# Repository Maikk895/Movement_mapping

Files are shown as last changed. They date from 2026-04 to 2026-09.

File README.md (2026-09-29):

Schemat projektu:




Layout płytki:






Wizualizacja:



Gotowy projekt:



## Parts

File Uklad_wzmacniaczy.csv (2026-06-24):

'Reference' | 'Qty' | 'Value' | 'DNP' | 'Exclude from BOM' | 'Exclude from Board' | 'Footprint' | 'Datasheet'
'BT1' | '1' | 'BK-18650-PC2' | '' | '' | '' | 'Uklad_wzmacniaczy_footprints:BAT_BK-18650-PC2' | 'https://www.digikey.co.uk/en/products/detail/mpd-memory-protection-devices/BK-18650-PC2/2079908'
'C1,C2,C3,C6,C10,C11,C16,C21,C23,C27,C31,C34,C35,C42,C43' | '15' | '10u' | '' | '' | '' | 'Capacitor_SMD:C_0603_1608Metric_Pad1.08x0.95mm_HandSolder' | ''
'C4,C5,C8,C9,C12,C17,C19,C20,C22,C24,C28,C44,C45,C46,C47' | '15' | '100n' | '' | '' | '' | 'Capacitor_SMD:C_0603_1608Metric_Pad1.08x0.95mm_HandSolder' | ''
'C7,C13,C18' | '3' | '1n' | '' | '' | '' | 'Capacitor_SMD:C_0603_1608Metric_Pad1.08x0.95mm_HandSolder' | ''
'C14,C15,C41' | '3' | '10n' | '' | '' | '' | 'Capacitor_SMD:C_0603_1608Metric_Pad1.08x0.95mm_HandSolder' | ''
'C25,C26,C30,C32,C33' | '5' | '4.7u' | '' | '' | '' | 'Capacitor_SMD:C_0603_1608Metric_Pad1.08x0.95mm_HandSolder' | ''
'C29' | '1' | '0.47u' | '' | '' | '' | 'Capacitor_SMD:C_0603_1608Metric_Pad1.08x0.95mm_HandSolder' | ''
'C36' | '1' | '1u' | '' | '' | '' | 'Capacitor_SMD:C_0603_1608Metric_Pad1.08x0.95mm_HandSolder' | ''
'C37' | '1' | '10p' | '' | '' | '' | 'Capacitor_SMD:C_0603_1608Metric_Pad1.08x0.95mm_HandSolder' | ''
'C38,C39,C40' | '3' | '22u' | '' | '' | '' | 'Capacitor_SMD:C_0603_1608Metric_Pad1.08x0.95mm_HandSolder' | ''
'D1' | '1' | 'LED' | '' | '' | '' | 'LED_SMD:LED_0805_2012Metric_Pad1.15x1.40mm_HandSolder' | ''
'J1' | '1' | 'SJ1-3523N' | '' | '' | '' | 'Uklad_wzmacniaczy_footprints:CUI_SJ1-3523N' | ''
'J2' | '1' | 'MEM2080-00-128-00-A' | '' | '' | '' | 'Uklad_wzmacniaczy_footprints:CONN_MEM2080-00-128-00-A_GCT' | 'MEM2080-00-128-00-A'
'J3' | '1' | 'Conn_01x10_Pin' | '' | '' | '' | 'Connector_PinHeader_2.54mm:PinHeader_2x05_P2.54mm_Horizontal' | ''
'L1' | '1' | '2.2u' | '' | '' | '' | 'Uklad_wzmacniaczy_footprints:INDC2520X120N' | ''
'L2' | '1' | '1u' | '' | '' | '' | 'Uklad_wzmacniaczy_footprints:IND_SPM6530T-1R0M120' | ''
'R1,R5,R7' | '3' | '33' | '' | '' | '' | 'Resistor_SMD:R_0603_1608Metric_Pad0.98x0.95mm_HandSolder' | ''
'R2,R9' | '2' | '220k' | '' | '' | '' | 'Resistor_SMD:R_0603_1608Metric_Pad0.98x0.95mm_HandSolder' | ''
'R3,R11' | '2' | '523' | '' | '' | '' | 'Resistor_SMD:R_0603_1608Metric_Pad0.98x0.95mm_HandSolder' | ''
'R4,R10' | '2' | '200-400k' | '' | '' | '' | 'Resistor_SMD:R_0603_1608Metric_Pad0.98x0.95mm_HandSolder' | ''
'R6,R8' | '2' | '10k' | '' | '' | '' | 'Resistor_SMD:R_0603_1608Metric_Pad0.98x0.95mm_HandSolder' | ''
'R12,R15' | '2' | '49.9k' | '' | '' | '' | 'Resistor_SMD:R_0603_1608Metric_Pad0.98x0.95mm_HandSolder' | ''
'R13' | '1' | '365k' | '' | '' | '' | 'Resistor_SMD:R_0603_1608Metric_Pad0.98x0.95mm_HandSolder' | ''
'R14' | '1' | '120k' | '' | '' | '' | 'Resistor_SMD:R_0603_1608Metric_Pad0.98x0.95mm_HandSolder' | ''
'R16' | '1' | '487k' | '' | '' | '' | 'Resistor_SMD:R_0603_1608Metric_Pad0.98x0.95mm_HandSolder' | ''
'R17' | '1' | '1M' | '' | '' | '' | 'Resistor_SMD:R_0603_1608Metric_Pad0.98x0.95mm_HandSolder' | ''
'R18' | '1' | '332k' | '' | '' | '' | 'Resistor_SMD:R_0603_1608Metric_Pad0.98x0.95mm_HandSolder' | ''
'R19' | '1' | '2k' | '' | '' | '' | 'Resistor_SMD:R_0603_1608Metric_Pad0.98x0.95mm_HandSolder' | ''
'R20' | '1' | '41.2k' | '' | '' | '' | 'Resistor_SMD:R_0603_1608Metric_Pad0.98x0.95mm_HandSolder' | ''
'U1' | '1' | 'OPA2388IDR' | '' | '' | '' | 'Uklad_wzmacniaczy_footprints:D0008A-IPC_A' | 'https://www.ti.com/lit/gpn/opa2388'
'U2' | '1' | 'REF2033QDDCRQ1' | '' | '' | '' | 'Uklad_wzmacniaczy_footprints:SOT-23-THIN-5_DDC_TEX' | 'https://www.ti.com/lit/gpn/ref20-q1'
'U3,U5' | '2' | 'AD8421ARMZ' | '' | '' | '' | 'Uklad_wzmacniaczy_footprints:RM_8_ADI' | 'https://www.analog.com/media/en/technical-documentation/data-sheets/AD8421-EP.pdf'
'U4' | '1' | 'OPA388IDR' | '' | '' | '' | 'Uklad_wzmacniaczy_footprints:D8_TEX' | 'https://www.ti.com/lit/gpn/opa388'
'U6' | '1' | 'TPD4E1B06DRLR' | '' | '' | '' | 'Uklad_wzmacniaczy_footprints:SOT50P160X60-6N' | ''
'U7,U10,U11' | '3' | 'AD5162BRMZ10-RL7' | '' | '' | '' | 'Uklad_wzmacniaczy_footprints:RM_10_ADI' | 'https://www.analog.com/media/en/technical-documentation/data-sheets/AD5162.pdf'
'U8' | '1' | 'LT3042EMSE-TRPBF' | '' | '' | '' | 'Uklad_wzmacniaczy_footprints:05-08-1664_ADI' | 'https://www.analog.com/media/en/technical-documentation/data-sheets/lt3042.pdf'
'U9' | '1' | 'TPS65135RTER' | '' | '' | '' | 'Uklad_wzmacniaczy_footprints:RTE16_1P7X1P7' | 'https://www.digikey.co.uk/en/products/detail/texas-instruments/TPS65135RTER/2782705'
'U12' | '1' | 'LT3094EMSE-TRPBF' | '' | '' | '' | 'Uklad_wzmacniaczy_footprints:MSE_05-08-1666_ADI' | 'https://www.analog.com/media/en/technical-documentation/data-sheets/LT3094.pdf'
'U13' | '1' | 'Nucleo-H755ZIQ-Morpho' | '' | '' | '' | 'Uklad_wzmacniaczy_footprints:Nucleo-H755ZIQ-Morpho' | ''
'U14' | '1' | 'TPS61236PRWLR' | '' | '' | '' | 'Uklad_wzmacniaczy_footprints:RWL0009A' | 'https://www.ti.com/lit/gpn/tps61236p'
'U15' | '1' | 'LD1117S50TR_SOT223' | '' | '' | '' | 'Package_TO_SOT_SMD:SOT-223-3_TabPin2' | 'http://www.st.com/st-web-ui/static/active/en/resource/technical/document/datasheet/CD00000544.pdf'

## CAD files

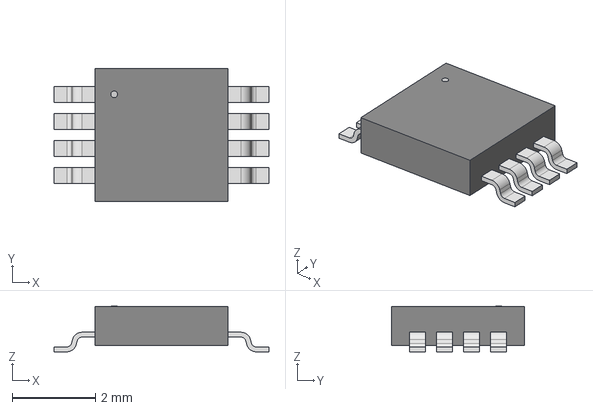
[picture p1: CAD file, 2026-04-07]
Parts/AD8421ARMZ/RM_8_ADI.step
5.16 x 3.20 x 1.09 mm

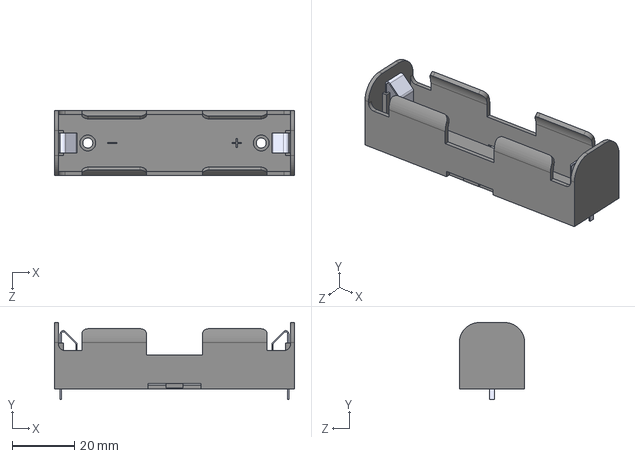
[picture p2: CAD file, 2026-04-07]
Parts/BK_18650_PC2/BK-18650-PC2.step
77.0 x 24.7 x 21.0 mm

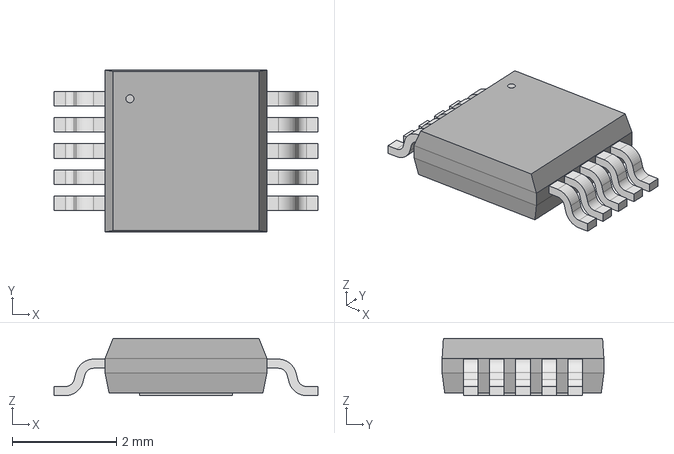
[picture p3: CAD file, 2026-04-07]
Parts/LT3042EMSE_TRPBF/05-08-1664_ADI.step
5.05 x 3.10 x 1.09 mm

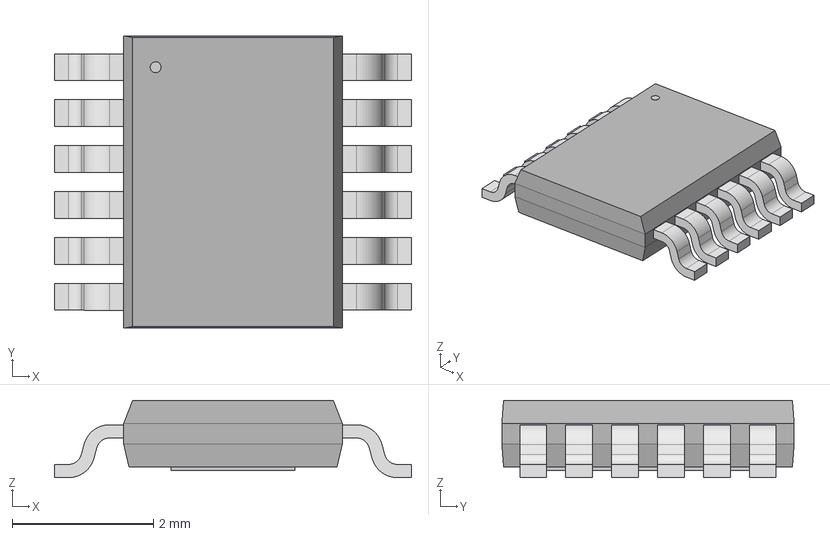
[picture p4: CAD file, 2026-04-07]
Parts/LT3094EMSE_TRPBF/MSE_05-08-1666_ADI.step
5.05 x 4.14 x 1.09 mm

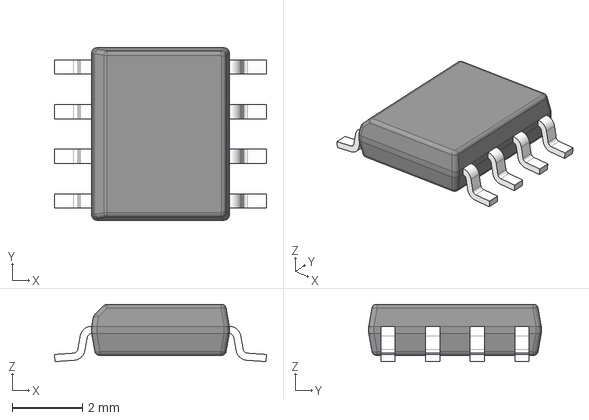
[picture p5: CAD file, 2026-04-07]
Parts/OPA189IDR/D0008A.stp
6.02 x 4.90 x 1.63 mm
BODY-SO
LEAD-D0008A x 8

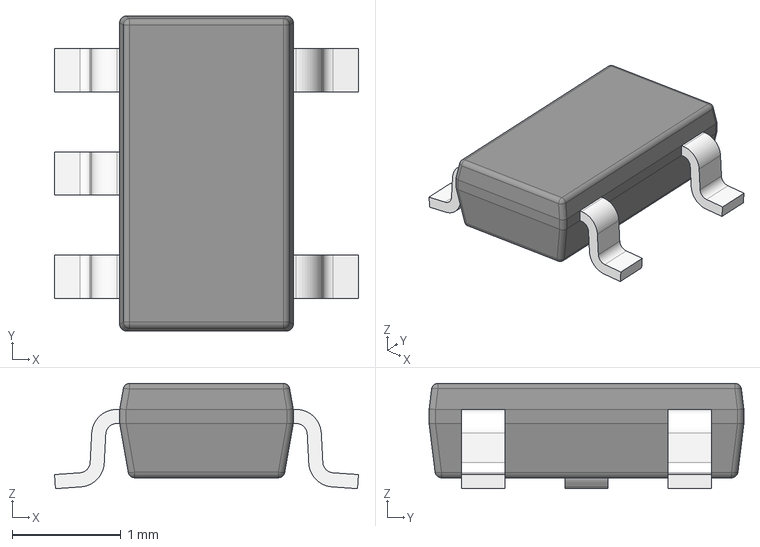
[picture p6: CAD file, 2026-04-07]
Parts/REF2033QDDCRQ1/DDC0005A.stp
2.80 x 2.90 x 0.97 mm
BODY-SOT
LEAD-SOT x 5

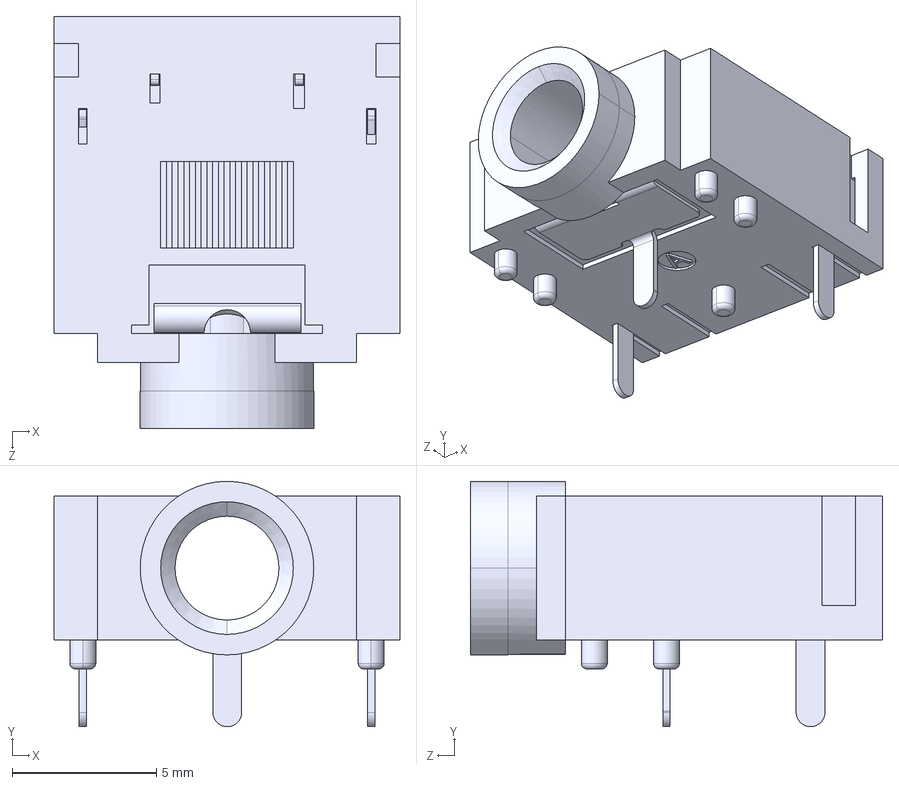
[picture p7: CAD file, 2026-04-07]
Parts/SJ1_3523N/SJ1-3523N.step
12.0 x 8.51 x 14.3 mm

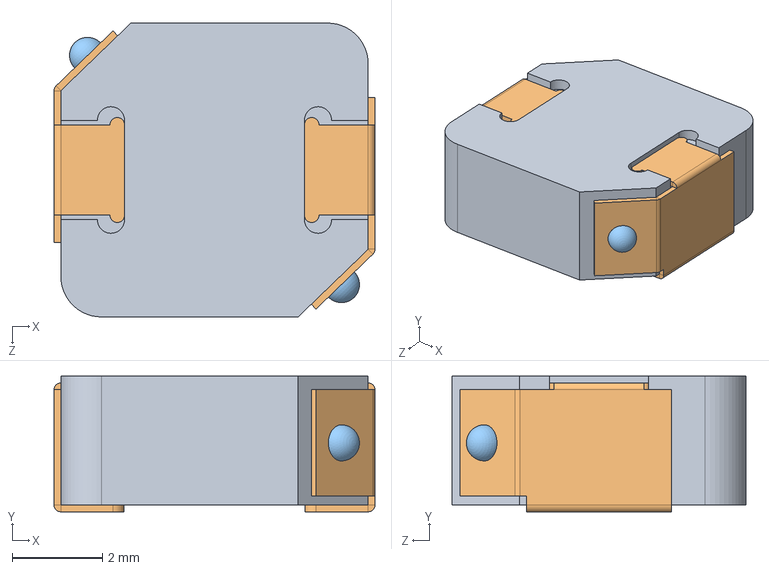
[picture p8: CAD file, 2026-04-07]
Parts/SPM6530T_1R0M120/SPM6530T-1R0M120.step
7.10 x 3.00 x 6.50 mm

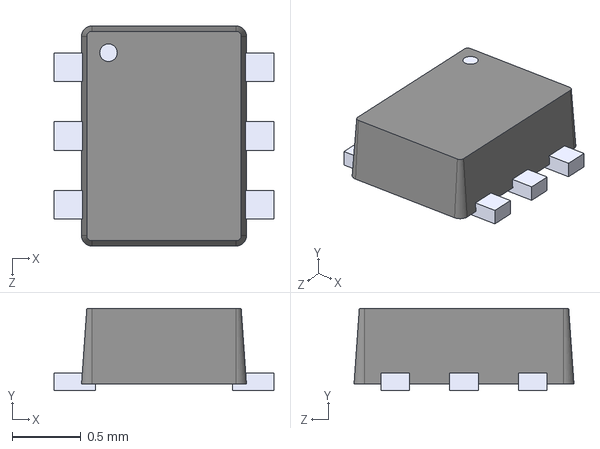
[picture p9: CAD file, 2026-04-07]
Parts/TPD4E1B06DRLR/TPD4E1B06DRLR.step
1.60 x 0.6 x 1.60 mm

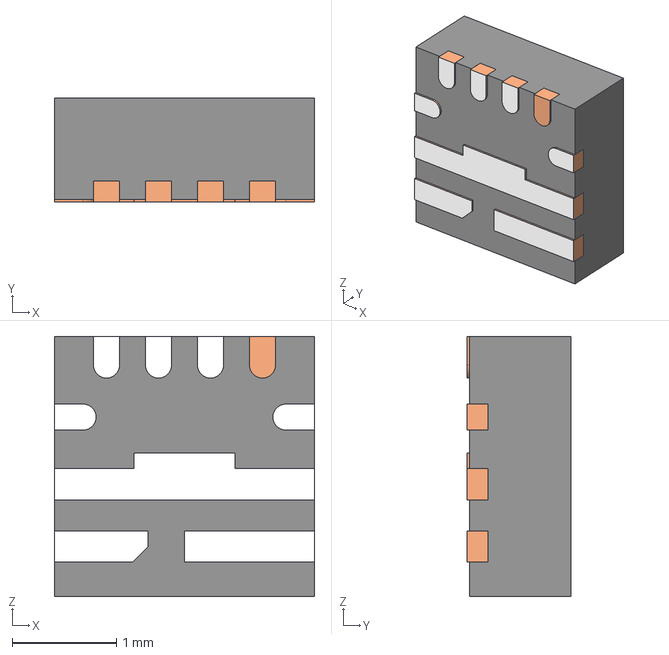
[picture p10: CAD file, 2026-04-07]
Parts/TPS61236PRWLR/RWL0009A.stp
2.50 x 1.00 x 2.50 mm
FRAME-RWL0009A
BODY-QFN

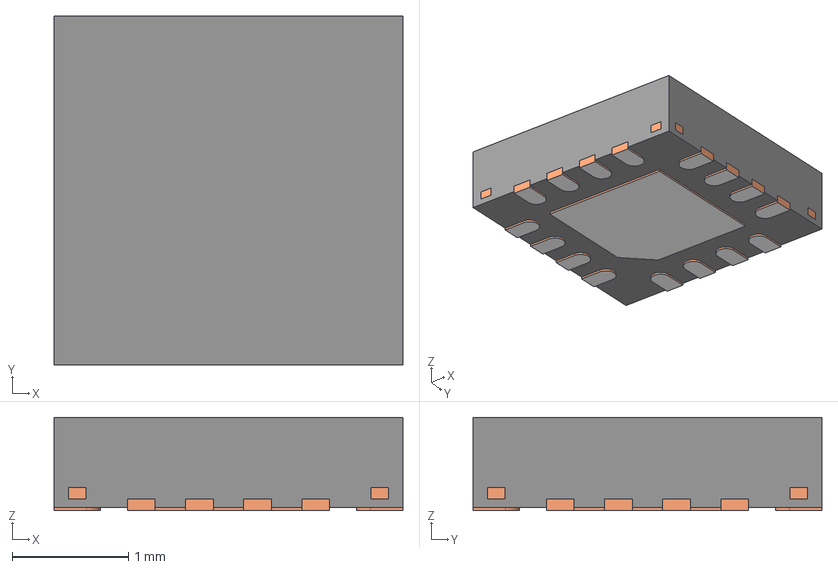
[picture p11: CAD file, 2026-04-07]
Parts/TPS65135RTER/RTE0016C.stp
3.00 x 3.00 x 0.8 mm
BODY-QFN
FRAME-RTE0016C
PIN1-ID

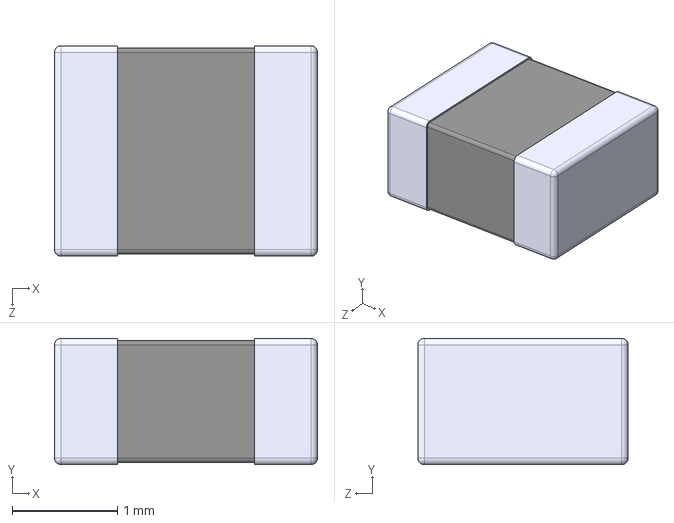
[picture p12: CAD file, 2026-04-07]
Parts/DFE252012P_2R2M_P2/DFE252012P-2R2M_P2.step
2.50 x 1.20 x 2.00 mm

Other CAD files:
Parts/OPA2388IDR/D0008A.stl

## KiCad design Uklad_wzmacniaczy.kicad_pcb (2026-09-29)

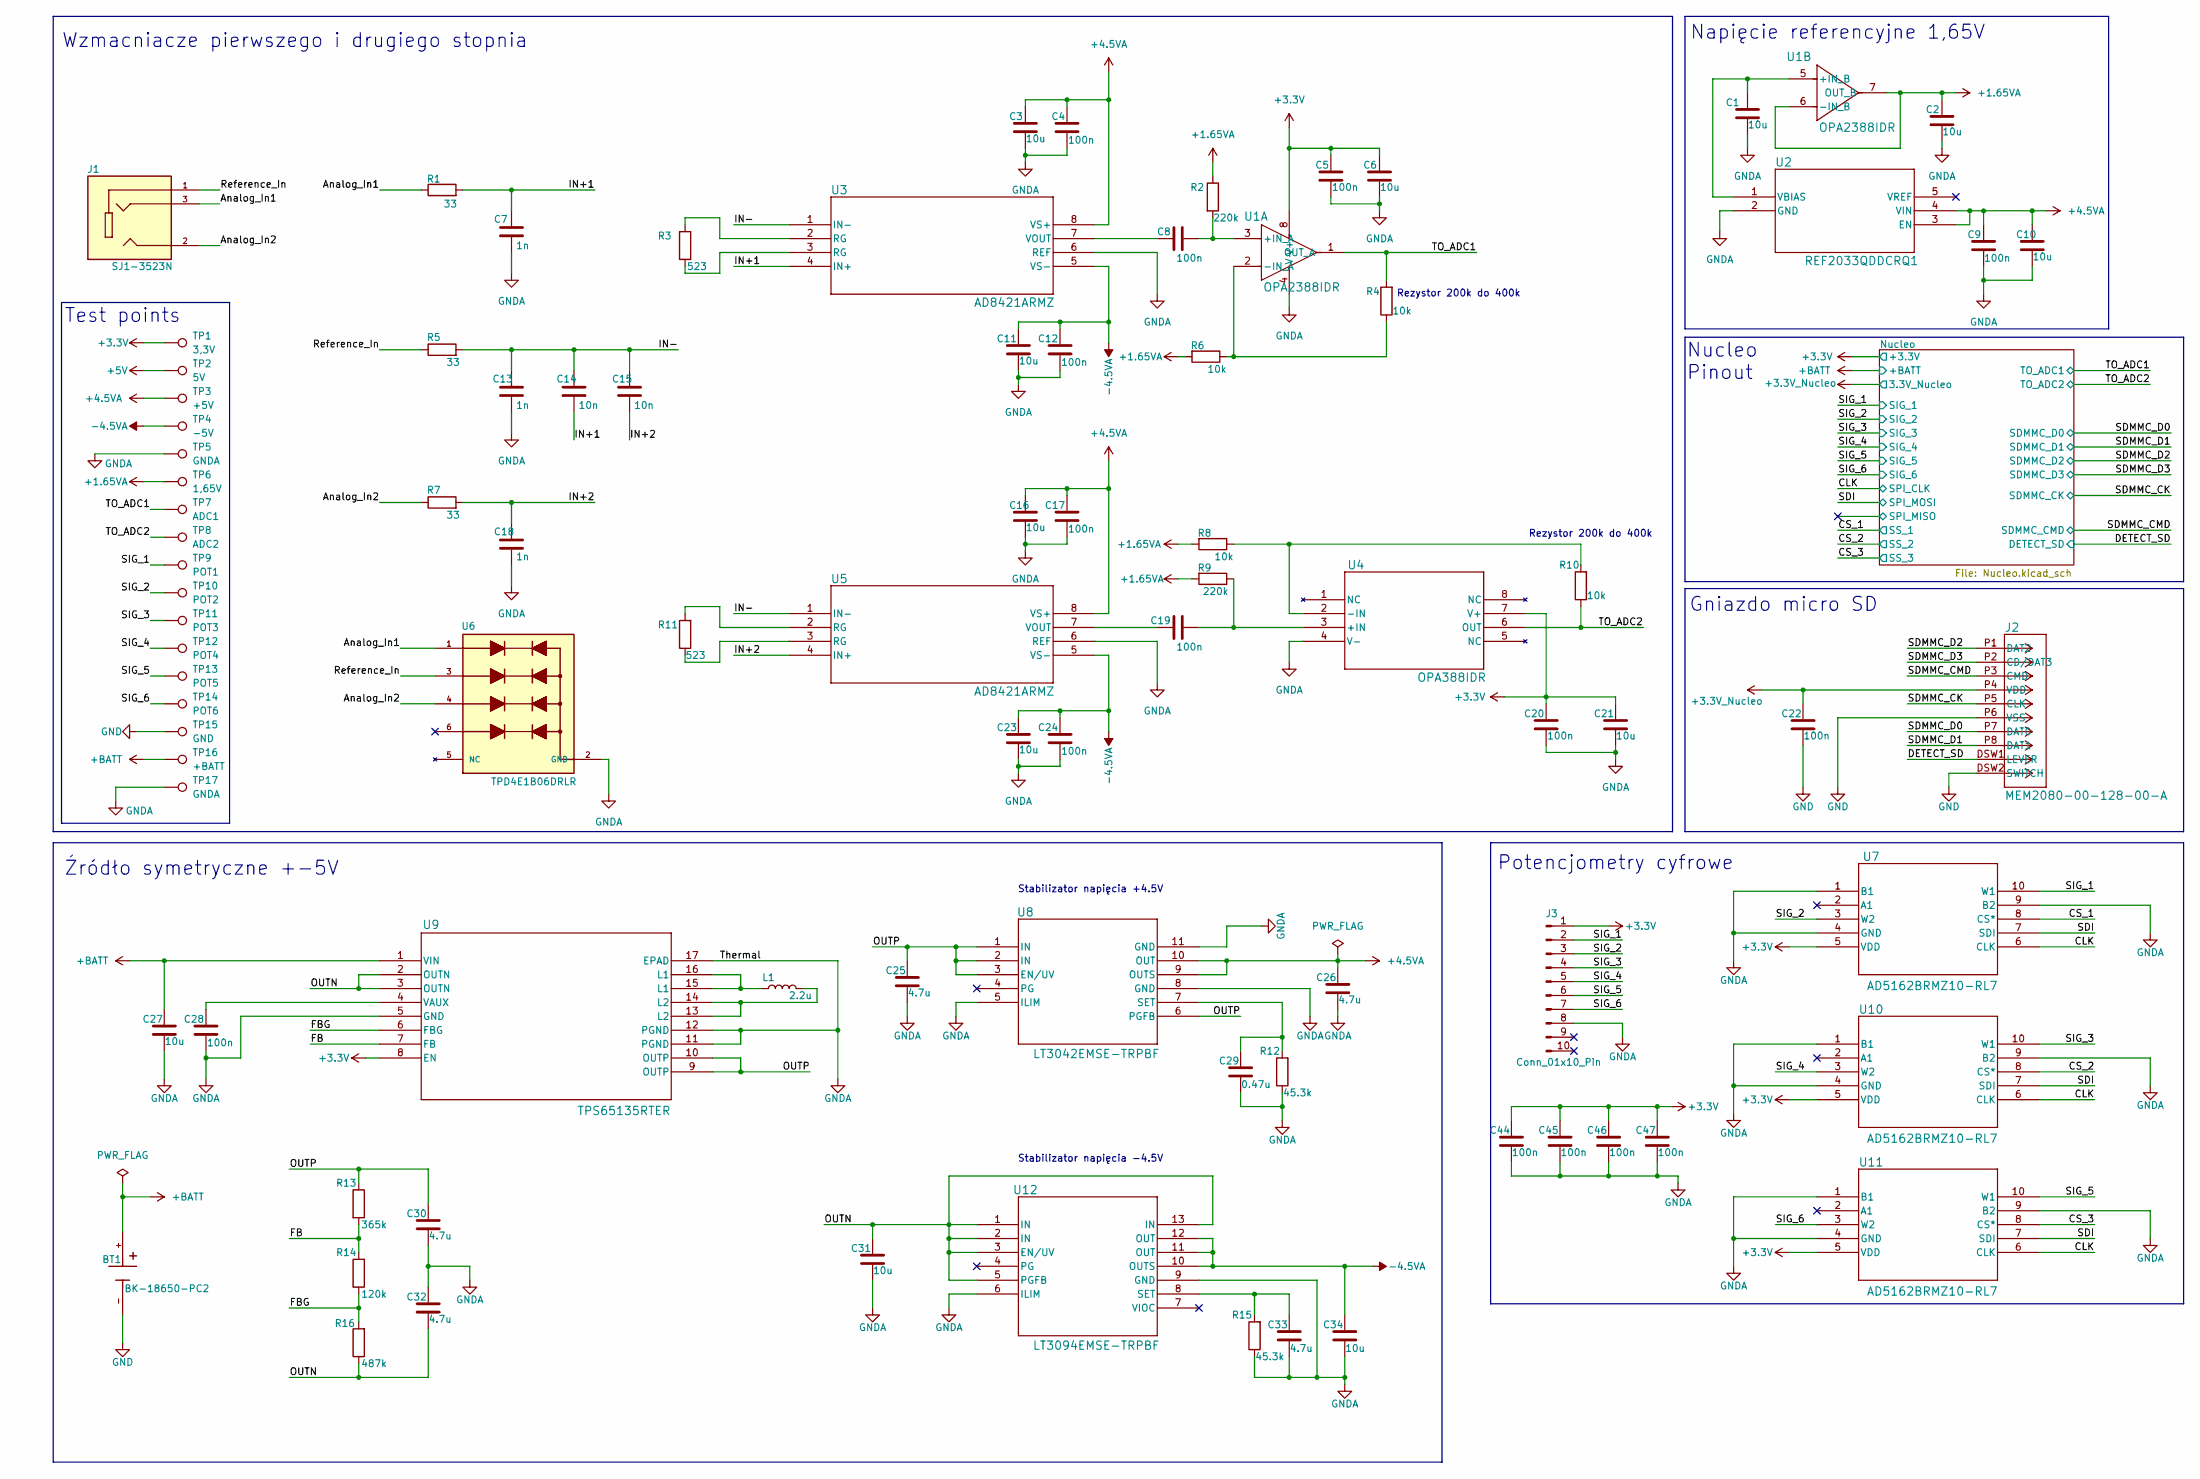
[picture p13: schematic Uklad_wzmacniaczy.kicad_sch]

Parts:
BT1: BK-18650-PC2; BAT_BK-18650-PC2; PARTREV F
C1, C2, C3, C6, C10, C11, C16, C21, C23, C27, C31, C34: 10u; C_0603_1608Metric_Pad1.08x0.95mm_HandSolder
C4, C5, C8, C9, C12, C17, C19, C20, C22, C24, C28, C44, C45, C46, C47: 100n; C_0603_1608Metric_Pad1.08x0.95mm_HandSolder
C7, C13, C18: 1n; C_0603_1608Metric_Pad1.08x0.95mm_HandSolder
C14, C15: 10n; C_0603_1608Metric_Pad1.08x0.95mm_HandSolder
C25, C26, C30, C32, C33: 4.7u; C_0603_1608Metric_Pad1.08x0.95mm_HandSolder
C29: 0.47u; C_0603_1608Metric_Pad1.08x0.95mm_HandSolder
J1: SJ1-3523N; CUI_SJ1-3523N; PARTREV 1.05
J2: MEM2080-00-128-00-A; CONN_MEM2080-00-128-00-A_GCT
J3: Conn_01x10_Pin; PinHeader_2x05_P2.54mm_Horizontal
L1: 2.2u; INDC2520X120N
R1, R5, R7: 33; R_0603_1608Metric_Pad0.98x0.95mm_HandSolder
R2, R9: 220k; R_0603_1608Metric_Pad0.98x0.95mm_HandSolder
R3, R11: 523; R_0603_1608Metric_Pad0.98x0.95mm_HandSolder
R4, R6, R8, R10: 10k; R_0603_1608Metric_Pad0.98x0.95mm_HandSolder
R12, R15: 45.3k; R_0603_1608Metric_Pad0.98x0.95mm_HandSolder
R13: 365k; R_0603_1608Metric_Pad0.98x0.95mm_HandSolder
R14: 120k; R_0603_1608Metric_Pad0.98x0.95mm_HandSolder
R16: 487k; R_0603_1608Metric_Pad0.98x0.95mm_HandSolder
TP1: 3,3V; TestPoint_Pad_D1.5mm
TP2: 5V; TestPoint_Pad_D1.5mm
TP3: +5V; TestPoint_Pad_D1.5mm
TP4: -5V; TestPoint_Pad_D1.5mm
TP5, TP17: GNDA; TestPoint_Pad_2.0x2.0mm
TP6: 1,65V; TestPoint_Pad_D1.5mm
TP7: ADC1; TestPoint_Pad_D1.5mm
TP8: ADC2; TestPoint_Pad_D1.5mm
TP9: POT1; TestPoint_Pad_D1.5mm
TP10: POT2; TestPoint_Pad_D1.5mm
TP11: POT3; TestPoint_Pad_D1.5mm
TP12: POT4; TestPoint_Pad_D1.5mm
TP13: POT5; TestPoint_Pad_D1.5mm
TP14: POT6; TestPoint_Pad_D1.5mm
TP15: GND; TestPoint_Pad_2.0x2.0mm
TP16: +BATT; TestPoint_Pad_D1.5mm
U1: OPA2388IDR; D0008A-IPC_A
U2: REF2033QDDCRQ1; SOT-23-THIN-5_DDC_TEX
U3, U5: AD8421ARMZ; RM_8_ADI
U4: OPA388IDR; D8_TEX
U6: TPD4E1B06DRLR; SOT50P160X60-6N; PARTREV E
U7, U10, U11: AD5162BRMZ10-RL7; RM_10_ADI
U8: LT3042EMSE-TRPBF; 05-08-1664_ADI
U9: TPS65135RTER; RTE16_1P7X1P7
U12: LT3094EMSE-TRPBF; MSE_05-08-1666_ADI

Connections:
+1.65VA: C2.1, R2.1, R6.2, R8.2, R9.2, TP6.1 (1_1), U1.6 (-IN_B), U1.7 (OUT_B)
+3.3V: C5.2, C6.1, C20.2, C21.1, C44.1, C45.1, C46.1, C47.1, J3.1, TP1.1 (1_1), U1.8 (V+), U4.7 (V+), U7.5 (VDD), U9.8 (EN), U10.5 (VDD), U11.5 (VDD); also elsewhere on the board
+3.3V_Nucleo: C22.1, J2.P4 (VDD); also elsewhere on the board
+5V: TP2.1 (1_1); also elsewhere on the board
+5VA: C3.1, C4.2, C9.1, C10.1, C16.1, C17.2, C26.1, TP3.1 (1_1), U2.3 (EN), U2.4 (VIN), U3.8 (VS+), U5.8 (VS+), U8.9 (OUTS), U8.10 (OUT)
+BATT: BT1.+, C27.1, TP16.1 (1_1), U9.1 (VIN); also elsewhere on the board
-5VA: C11.1, C12.2, C23.1, C24.2, C34.1, TP4.1 (1_1), U3.5 (VS-), U5.5 (VS-), U12.10 (OUTS), U12.11 (OUT), U12.12 (OUT)
/Analog_In1: J1.3, R1.1, U6.1
/Analog_In2: J1.2, R7.1, U6.4
/CLK: U7.6 (CLK), U10.6 (CLK), U11.6 (CLK); also elsewhere on the board
/CS_1: U7.8 (CS*); also elsewhere on the board
/CS_2: U10.8 (CS*); also elsewhere on the board
/CS_3: U11.8 (CS*); also elsewhere on the board
/DETECT_SD: J2.DSW1 (LEVER); also elsewhere on the board
/FB: R13.2, R14.2, U9.7 (FB)
/FBG: R14.1, R16.2, U9.6 (FBG)
/IN+1: C7.1, C14.2, R1.2, U3.4 (IN+)
/IN+2: C15.2, C18.1, R7.2, U5.4 (IN+)
/IN-: C13.1, C14.1, C15.1, R5.2, U3.1 (IN-), U5.1 (IN-)
/OUTN: C31.1, C32.2, R16.1, U9.2 (OUTN), U9.3 (OUTN), U12.1 (IN), U12.2 (IN), U12.3 (EN/UV), U12.5 (PGFB), U12.13 (IN)
/OUTP: C25.1, C30.1, R13.1, U8.1 (IN), U8.2 (IN), U8.3 (EN/UV), U8.6 (PGFB), U9.9 (OUTP), U9.10 (OUTP)
/Reference_In: J1.1, R5.1, U6.3
/SDI: U7.7 (SDI), U10.7 (SDI), U11.7 (SDI); also elsewhere on the board
/SDMMC_CK: J2.P5 (CLK); also elsewhere on the board
/SDMMC_CMD: J2.P3 (CMD); also elsewhere on the board
/SDMMC_D0: J2.P7 (DAT0); also elsewhere on the board
/SDMMC_D1: J2.P8 (DAT1); also elsewhere on the board
/SDMMC_D2: J2.P1 (DAT2); also elsewhere on the board
/SDMMC_D3: J2.P2 (CD/DAT3); also elsewhere on the board
/SIG_1: J3.2, TP9.1 (1_1), U7.10 (W1); also elsewhere on the board
/SIG_2: J3.3, TP10.1 (1_1), U7.3 (W2); also elsewhere on the board
/SIG_3: J3.4, TP11.1 (1_1), U10.10 (W1); also elsewhere on the board
/SIG_4: J3.5, TP12.1 (1_1), U10.3 (W2); also elsewhere on the board
/SIG_5: J3.6, TP13.1 (1_1), U11.10 (W1); also elsewhere on the board
/SIG_6: J3.7, TP14.1 (1_1), U11.3 (W2); also elsewhere on the board
/TO_ADC1: R4.2, TP7.1 (1_1), U1.1 (OUT_A); also elsewhere on the board
/TO_ADC2: R10.1, TP8.1 (1_1), U4.6 (OUT); also elsewhere on the board
GND: BT1.-, C22.2, J2.DSW2 (SWITCH), J2.P6 (VSS), TP15.1 (1_1); also elsewhere on the board
GNDA: C1.2, C2.2, C3.2, C4.1, C5.1, C6.2, C7.2, C9.2, C10.2, C11.2, C12.1, C13.2, C16.2, C17.1, C18.2, C20.1, C21.2, C23.2, C24.1, C25.2, C26.2, C27.2, C28.1, C29.2, C30.2, C31.2, C32.1, C33.2, C34.2, C44.2, C45.2, C46.2, C47.2, J3.8, R12.1, R15.1, TP5.1 (1_1), TP17.1 (1_1), U1.4 (V-), U2.2 (GND), U3.6 (REF), U4.4 (V-), U5.6 (REF), U6.2 (GND_2), U7.1 (B1), U7.4 (GND), U7.9 (B2), U8.5 (ILIM), U8.8 (GND), U8.11 (GND), U9.5 (GND), U9.11 (PGND), U9.12 (PGND), U9.17 (EPAD), U9.EPAD, U10.1 (B1), U10.4 (GND), U10.9 (B2), U11.1 (B1), U11.4 (GND), U11.9 (B2), U12.6 (ILIM), U12.9 (GND); also elsewhere on the board
unnamed: L1.1, U9.15 (L1), U9.16 (L1)
unnamed: L1.2, U9.13 (L2), U9.14 (L2)
unnamed: R3.1, U3.3 (RG)
unnamed: R3.2, U3.2 (RG)
unnamed: R11.1, U5.3 (RG)
unnamed: R11.2, U5.2 (RG)
unnamed: C8.2, R2.2, U1.3 (+IN_A)
unnamed: R4.1, R6.1, U1.2 (-IN_A)
unnamed: C1.1, U1.5 (+IN_B), U2.1 (VBIAS)
unnamed: C8.1, U3.7 (VOUT)
unnamed: C19.2, R9.1, U4.3 (+IN)
unnamed: R8.1, R10.2, U4.2 (-IN)
unnamed: C19.1, U5.7 (VOUT)
unnamed: C29.1, R12.2, U8.7 (SET)
unnamed: C28.2, U9.4 (VAUX)
unnamed: C33.1, R15.2, U12.8 (SET)

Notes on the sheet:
Napięcie referencyjne 1,65V
Źródło symetryczne +-5V
Stabilizator napięcia -4.5V
Nucleo Pinout
Potencjometry cyfrowe
Gniazdo micro SD
Wzmacniacze pierwszego i drugiego stopnia
Rezystor 200k do 400k
Test points
Stabilizator napięcia +4.5V

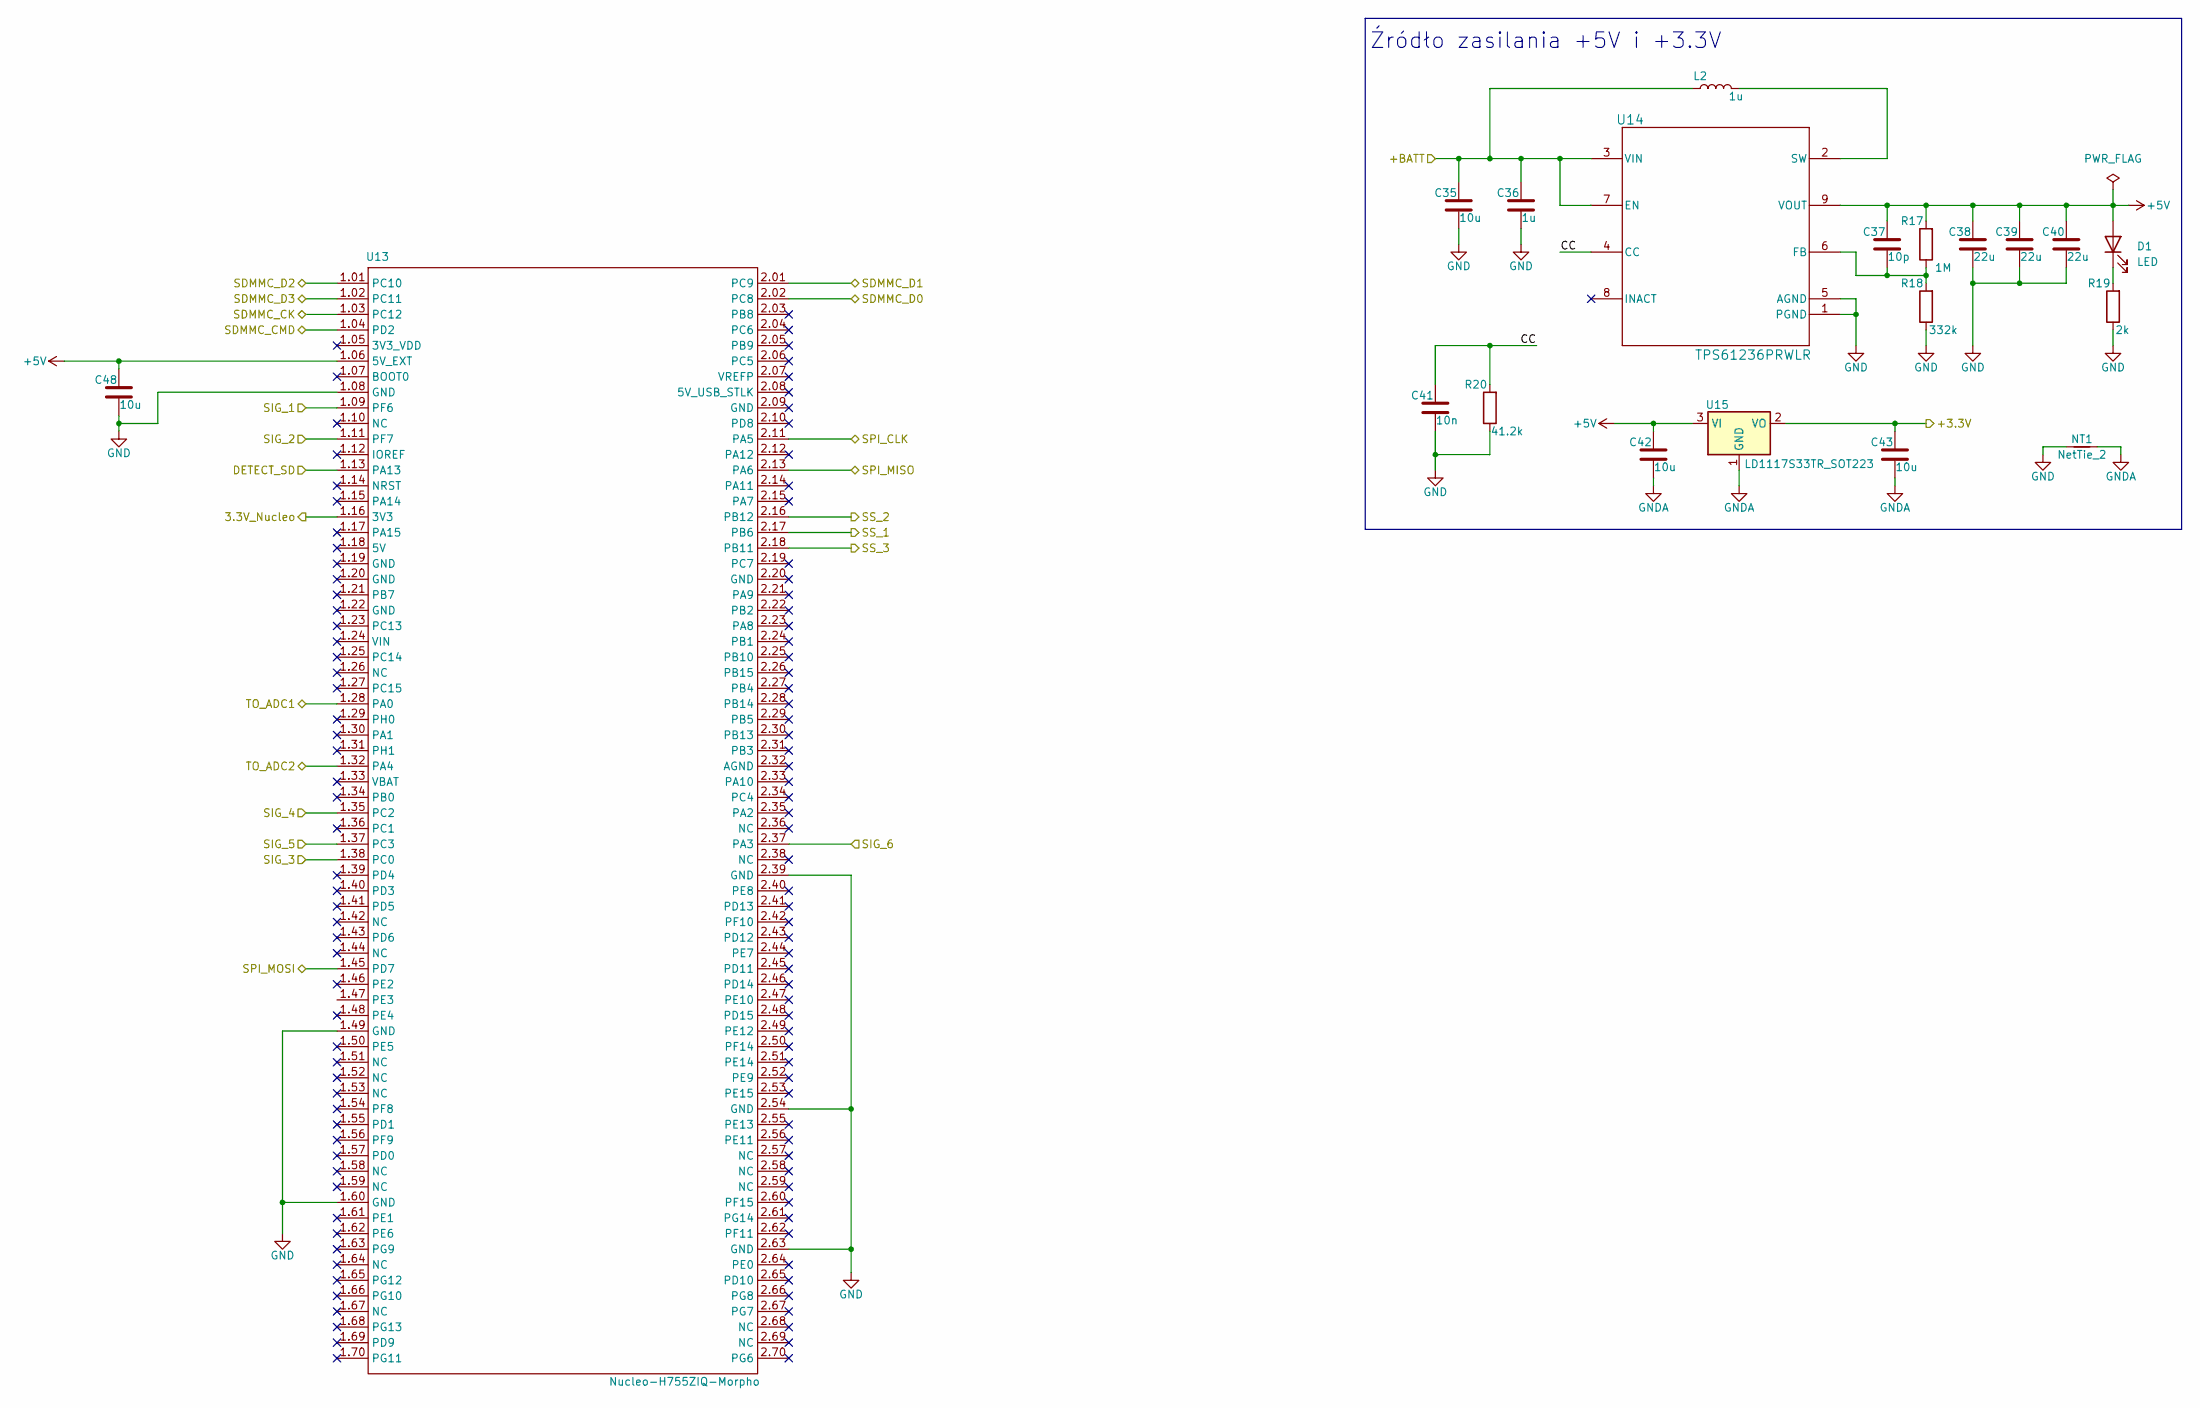
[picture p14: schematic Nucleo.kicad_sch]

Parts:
C35, C42, C43, C48: 10u; C_0603_1608Metric_Pad1.08x0.95mm_HandSolder
C36: 1u; C_0603_1608Metric_Pad1.08x0.95mm_HandSolder
C37: 10p; C_0603_1608Metric_Pad1.08x0.95mm_HandSolder
C38, C39, C40: 22u; C_0603_1608Metric_Pad1.08x0.95mm_HandSolder
C41: 10n; C_0603_1608Metric_Pad1.08x0.95mm_HandSolder
D1: LED; LED_0805_2012Metric_Pad1.15x1.40mm_HandSolder
L2: 1u; IND_SPM6530T-1R0M120
NT1: NetTie_2; NetTie-2_SMD_Pad0.5mm
R17: 1M; R_0603_1608Metric_Pad0.98x0.95mm_HandSolder
R18: 332k; R_0603_1608Metric_Pad0.98x0.95mm_HandSolder
R19: 2k; R_0603_1608Metric_Pad0.98x0.95mm_HandSolder
R20: 41.2k; R_0603_1608Metric_Pad0.98x0.95mm_HandSolder
U13: Nucleo-H755ZIQ-Morpho
U14: TPS61236PRWLR; RWL0009A
U15: LD1117S33TR_SOT223; SOT-223-3_TabPin2

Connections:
+3.3V: C43.1, U15.2 (VO); also elsewhere on the board
+3.3V_Nucleo: U13.1.16 (3V3); also elsewhere on the board
+5V: C37.1, C38.1, C39.1, C40.1, C42.1, C48.1, D1.2 (A), R17.2, U13.1.06 (5V_EXT), U14.9 (VOUT), U15.3 (VI); also elsewhere on the board
+BATT: C35.1, C36.1, L2.1, U14.3 (VIN), U14.7 (EN); also elsewhere on the board
/CLK: U13.2.11 (PA5); also elsewhere on the board
/CS_1: U13.2.17 (PB6); also elsewhere on the board
/CS_2: U13.2.16 (PB12); also elsewhere on the board
/CS_3: U13.2.18 (PB11); also elsewhere on the board
/DETECT_SD: U13.1.13 (PA13); also elsewhere on the board
/Nucleo/CC: C41.1, R20.2, U14.4 (CC)
/Nucleo/SPI_MISO: U13.2.13 (PA6)
/SDI: U13.1.45 (PD7); also elsewhere on the board
/SDMMC_CK: U13.1.03 (PC12); also elsewhere on the board
/SDMMC_CMD: U13.1.04 (PD2); also elsewhere on the board
/SDMMC_D0: U13.2.02 (PC8); also elsewhere on the board
/SDMMC_D1: U13.2.01 (PC9); also elsewhere on the board
/SDMMC_D2: U13.1.01 (PC10); also elsewhere on the board
/SDMMC_D3: U13.1.02 (PC11); also elsewhere on the board
/SIG_1: U13.1.09 (PF6); also elsewhere on the board
/SIG_2: U13.1.11 (PF7); also elsewhere on the board
/SIG_3: U13.1.38 (PC0); also elsewhere on the board
/SIG_4: U13.1.35 (PC2); also elsewhere on the board
/SIG_5: U13.1.37 (PC3); also elsewhere on the board
/SIG_6: U13.2.37 (PA3); also elsewhere on the board
/TO_ADC1: U13.1.28 (PA0); also elsewhere on the board
/TO_ADC2: U13.1.32 (PA4); also elsewhere on the board
GND: C35.2, C36.2, C38.2, C39.2, C40.2, C41.2, C48.2, NT1.1, R18.1, R19.1, R20.1, U13.1.08 (GND), U13.1.49 (GND), U13.1.60 (GND), U13.2.39 (GND), U13.2.54 (GND), U13.2.63 (GND), U14.1 (PGND), U14.5 (AGND); also elsewhere on the board
GNDA: C42.2, C43.2, NT1.2, U15.1 (GND); also elsewhere on the board
unnamed: D1.1 (K), R19.2
unnamed: C37.2, R17.1, R18.2, U14.6 (FB)
unnamed: L2.2, U14.2 (SW)

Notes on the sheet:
Źródło zasilania +5V i +3.3V

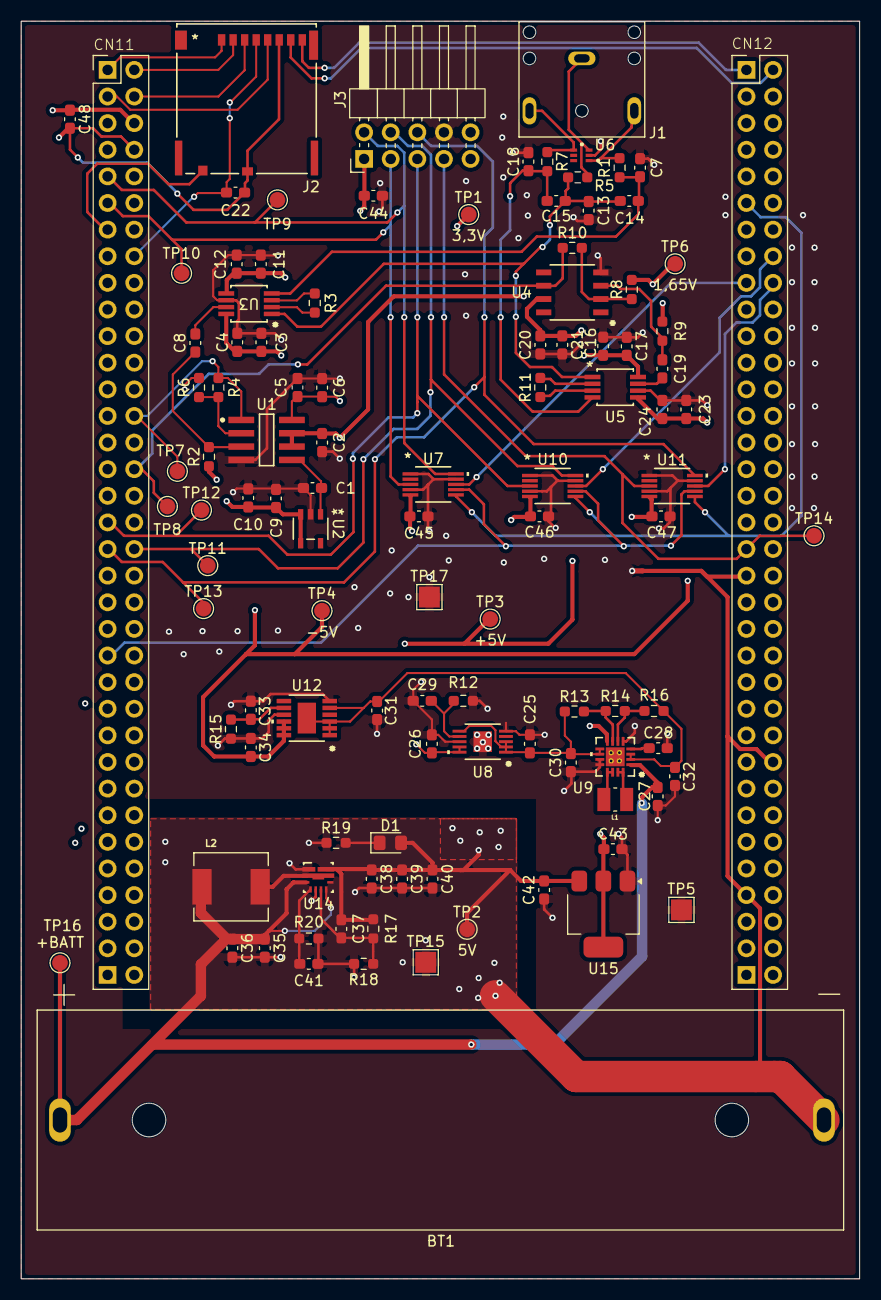
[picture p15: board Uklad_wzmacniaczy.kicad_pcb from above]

Board: 4 copper layers, 80.0 x 120.0 mm, 108 parts (0 on the bottom side), 59 nets.

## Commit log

2026-04-08 Footprint and symbol for Nucleo-h755ZIQ added
    [Uklad_wzmacniaczy.kicad_sch, untitled.kicad_sch]
2026-04-14 PCB layout first commit, minor fix in schematic
    [Nucleo.kicad_sch, Uklad_wzmacniaczy.kicad_pcb, Uklad_wzmacniaczy.kicad_sch]
2026-04-15 Schematic minor change Vbat -> 3.3V, PCB layout: +5V, -5V
    [Uklad_wzmacniaczy.kicad_pcb, Uklad_wzmacniaczy.kicad_sch]
2026-05-25 New STM footprint, changed PCB layout, added pin connector
    [Nucleo.kicad_sch, Uklad_wzmacniaczy.kicad_pcb, Uklad_wzmacniaczy.kicad_sch]
2026-05-27 Nucleo-shield pins change
    [Nucleo.kicad_sch, Uklad_wzmacniaczy.kicad_pcb, Uklad_wzmacniaczy.kicad_sch]
2026-06-24 Layout major change, .gitignore added
    [Nucleo.kicad_sch, Uklad_wzmacniaczy.csv, Uklad_wzmacniaczy.kicad_pcb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]
2026-06-29 Layout and schematic minor changes
    [Uklad_wzmacniaczy.kicad_pcb, Uklad_wzmacniaczy.kicad_sch]
2026-07-02 Errors in pcb layout removed, footprints fixed, microvias changed to regular vias
    [Nucleo.kicad_sch, Uklad_wzmacniaczy.kicad_pcb, Uklad_wzmacniaczy.kicad_sch]
2026-08-04 Vias fixed, generated gerber files
    [Nucleo.kicad_sch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]
2026-09-29 Minor fixes
    [Uklad_wzmacniaczy.kicad_pcb, Uklad_wzmacniaczy.kicad_sch]
2026-09-29 3d models added
    [Uklad_wzmacniaczy.kicad_pcb]
